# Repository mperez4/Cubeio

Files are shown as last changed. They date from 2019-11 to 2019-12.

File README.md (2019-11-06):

# Cubeio
An active meeting engagement tool designed to foster and facilitate decision-making, meaningful dialogue and equal input.
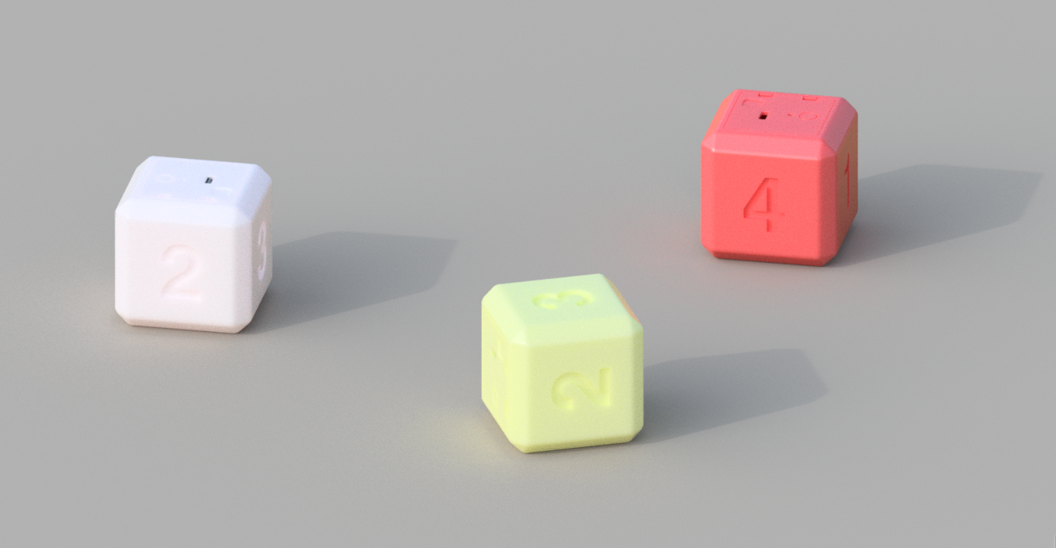
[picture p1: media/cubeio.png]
Cubeio


## Getting Started
If this is your first time using the particle, please refer to the [quickstart guide](https://docs.particle.io/quickstart/photon/). The following instructions are written for Mac. If you are using Particle's [web compiler](build.particle.io), search for the `Cubeio` library under libraries. 

### 1. Install [Particle CLI](https://docs.particle.io/tutorials/developer-tools/cli/)

```
$ npm install -g particle-cli
```

### 2. Create a new project

```
$ particle project create
```

### 3. Add library to your project
This should create the library scaffolding necessary to import the library from within your project directory. 

```
$ particle library add Cubeio
```

```
$ particle library view Cubeio
```

## Usage
Once you install the library through the Particle CLI, you should be ready to go.
```c++
#include "Cubeio.h"

Cubeio mycube(D6, D1, A1,A2,A3);
```
Your object declaration might be constructed differently depending on the hardware. Please view the hardware revision and pinouts under `/hardware`.
View the `/examples` and `/src` files to get detailed information about the library.

## Examples
There is a pretty handy script called `upload.sh` inside of every example. `upload.sh` puts the particle device in DFU mode, compiles the cpp file, and uploads the firmware to the device. Make sure that your cube's particle is connected via USB to your computer.
```bash
$ ./examples/set-calibration/upload.sh
```
This script was working well before I upgraded to Catalina... For now, you can use Particle's cloud compiler, which works fine it just takes longer... 

## Hardware
Cubeio uses an Analog Devices [ADXL325](https://www.analog.com/media/en/technical-documentation/data-sheets/ADXL325.pdf) 3-axis accelerometer to calculate the roll and pitch (±5 g) of the cube, a Microchip [MCP73831](http://ww1.microchip.com/downloads/en/DeviceDoc/20001984g.pdf) Li-Polymer charge managment controller, a Worldsemi [WS2812](https://cdn-shop.adafruit.com/datasheets/WS2812.pdf) RGB LED, a single [Schmitt-Trigger](https://datasheet.lcsc.com/szlcsc/ON-Semicon-ON-MC74VHC1G14DTT1G_C242264.pdf) inverter, and a button among other hardware components.
Please view the hardware revision and pinouts under `/hardware`.
You can use this library with any microcontroller if you are using an ADXLxxx chip on its own. You may set the analog pins to your microcontroller and it will work the same. This is intended for the cubeio hardware, so there are no default values set in the `Cubeio object()` object. This library will work for [this](https://www.adafruit.com/product/163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) device from Adafruit.

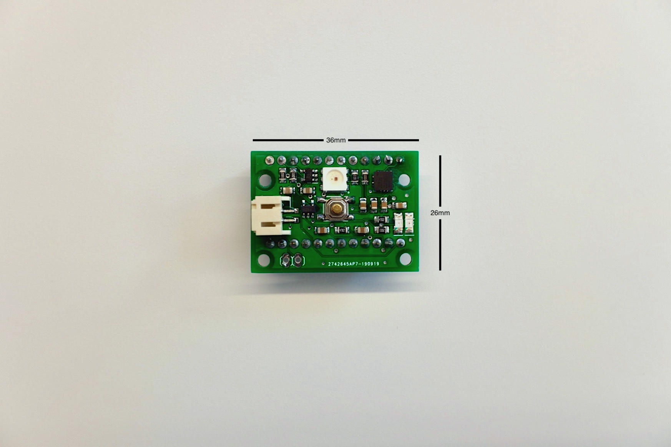
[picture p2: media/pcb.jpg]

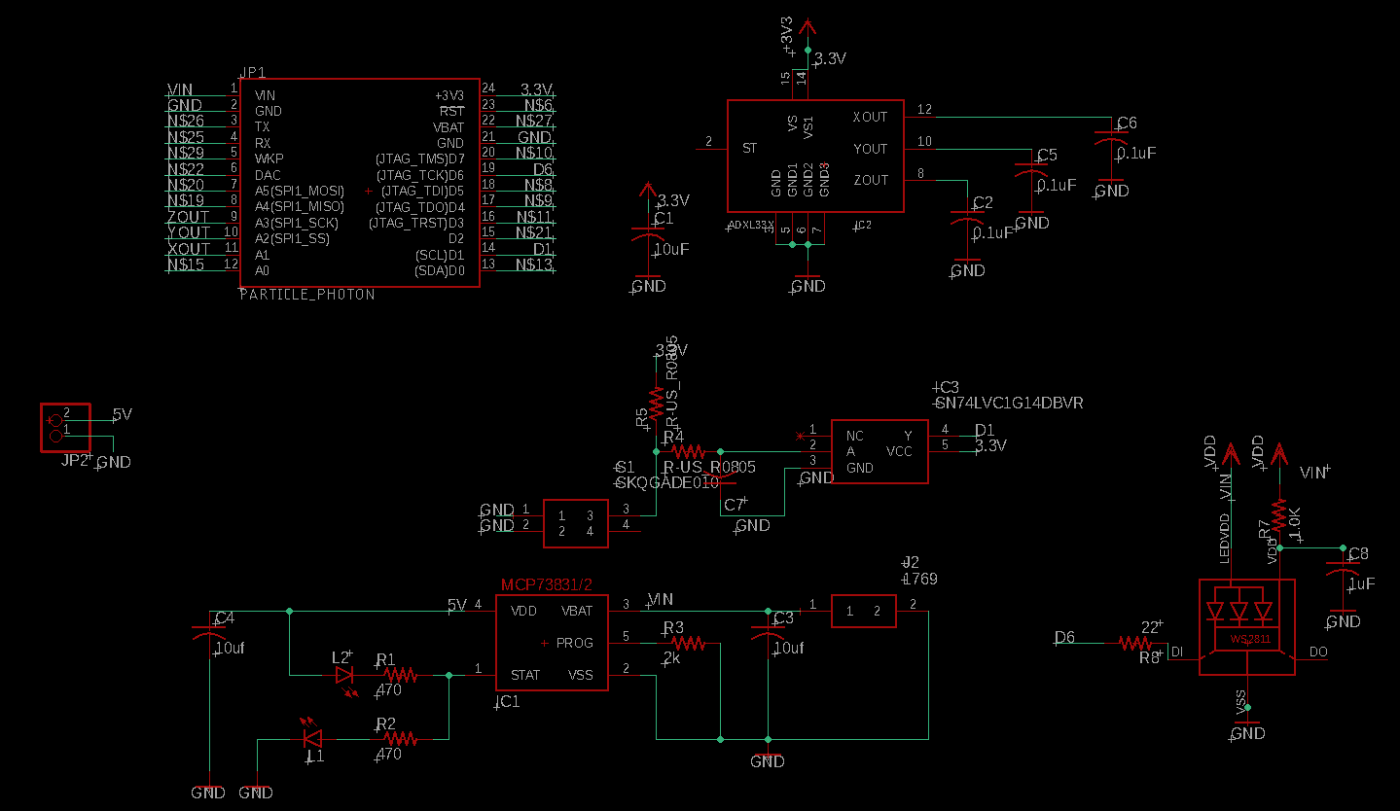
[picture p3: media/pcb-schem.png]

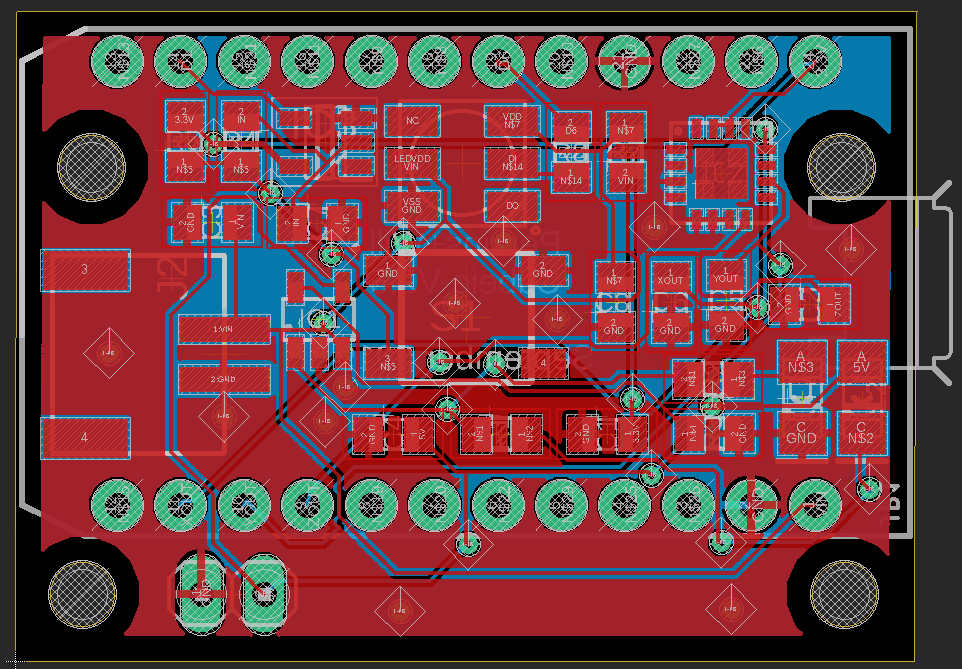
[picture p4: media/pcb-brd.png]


## Contribution
I don't think that the Particle CLI allows branching/merging of libraries from multiple users. This may change, so for now you are welcome to submit pull requests and i will publish the changes.

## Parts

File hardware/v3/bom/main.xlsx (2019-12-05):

Comment | Designator | Footprint | LCSC Part #（optional）
10uF | C1, C3, C4 | 0805 | C161260
100nF | C2, C5, C6, C7 | 0805 | C28233
1uF | C8 | 0805 | C28323
MCP73831T-2ATI/OT | IC1 | SOT-23-5 | C14879
ADXL325BCPZ-RL7 | IC2 | LFCSP-16 | C208133
SN74LVC1G14DBVR | IC3 | SOT-23-5 | C7835
AFC07-S06ECC-00 | J1 | 6P | C11083
TJ-S3216SW9TGLC9Y-A5 | L1 | 1206 | C192676
TJ-S3216SW9TGLC7K-A5 | L2 | 1206 | C192677
WS2812S | LED1 | 5050 | C114584
470ohms | R1, R2 | 0805 | C119076
2K | R3 | 0805 | C132365
10k | R4, R5 | 0805 | C84376
1K | R7 | 0805 | C95781
22Ohms | R8 | 0805 | C25295
TSA053G25-250T | S1 | SMD | C331512

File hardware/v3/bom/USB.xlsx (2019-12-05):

Comment | Designator | Footprint | LCSC Part #（optional）
ICC 10118192-0001LF | J3 | SMD | C132564
AFC07-S06ECC-00 | J1 | 6P | C11083

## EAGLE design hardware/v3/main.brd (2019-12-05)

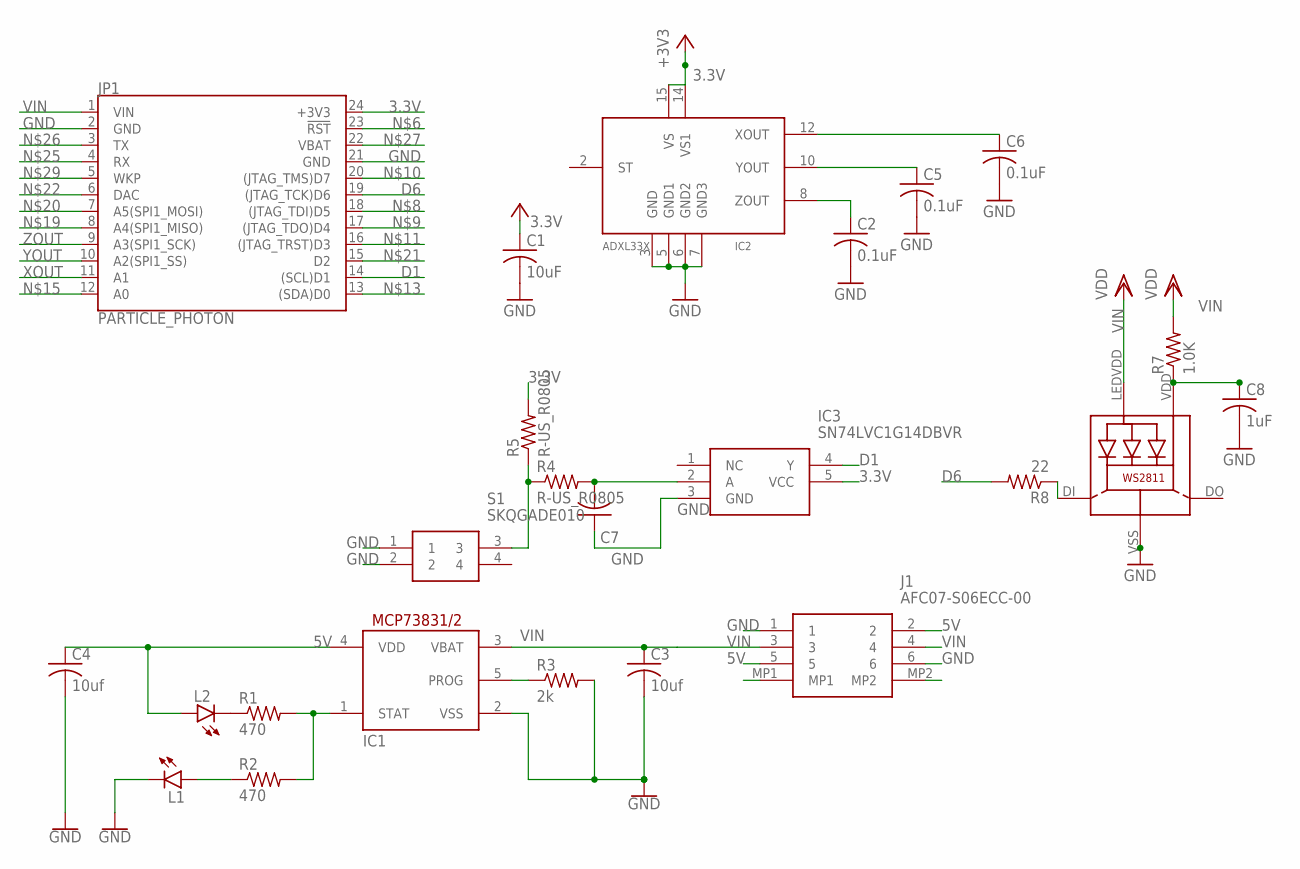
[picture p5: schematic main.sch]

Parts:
C1: 10uF; ADAFRUIT_C0805K
C2, C5, C6: 0.1uF; ADAFRUIT_C0805K
C3, C4: 10uf; ADAFRUIT_C0805K
C7: ADAFRUIT_C-USC0805K; ADAFRUIT_C0805K
C8: 1uF; ADAFRUIT_C0805K
IC1: MCP73831/OT; SOT23-5L
IC2: ADXL33X; 16LCSP
IC3: SN74LVC1G14DBVR; SOT95P280X145-5N
J1: AFC07-S06ECC-00; AFC07S06ECC00
JP1: PARTICLE_PHOTON
L1: green; FKIT-LED-1206
L2: blue; FKIT-LED-1206
LED1: WS28115050
R1, R2: 470; R0805
R3: 2k; R0805
R4, R5: R-US_R0805; R0805
R7: 1.0K; R0805
R8: 22; R0805
S1: SKQGADE010; SKQGAKE010

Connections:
3.3V: C1.1, IC2.14 (VS1), IC2.15 (VS), IC3.5 (VCC), JP1.24 (+3V3), R5.2
5V: C4.1, IC1.4 (VDD), J1.2, J1.5, L2.A
D1: IC3.4 (Y), JP1.14 ((SCL)D1)
D6: JP1.19 ((JTAG_TCK)D6), R8.2
GND: C1.2, C2.2, C3.2, C4.2, C5.2, C6.2, C7.1, C8.2, IC1.2 (VSS), IC2.3 (GND), IC2.5 (GND1), IC2.6 (GND2), IC2.7 (GND3), IC3.3 (GND), J1.1, J1.6, JP1.2 (GND), JP1.21 (GND), L1.C, LED1.VSS (GND), R3.2, S1.1, S1.2
IN: C7.2, IC3.2 (A), R4.2
unnamed: IC1.1 (STAT), R1.2, R2.2
unnamed: L2.C, R1.1
unnamed: L1.A, R2.1
unnamed: IC1.5 (PROG), R3.1
unnamed: R4.1, R5.1, S1.3
unnamed: C8.1, LED1.VDD, R7.1
unnamed: LED1.DI, R8.1
VIN: C3.1, IC1.3 (VBAT), J1.3, J1.4, JP1.1 (VIN), LED1.LEDVDD, R7.2
XOUT: C6.1, IC2.12 (XOUT), JP1.11 (A1)
YOUT: C5.1, IC2.10 (YOUT), JP1.10 (A2(SPI1_SS))
ZOUT: C2.1, IC2.8 (ZOUT), JP1.9 (A3(SPI1_SCK))

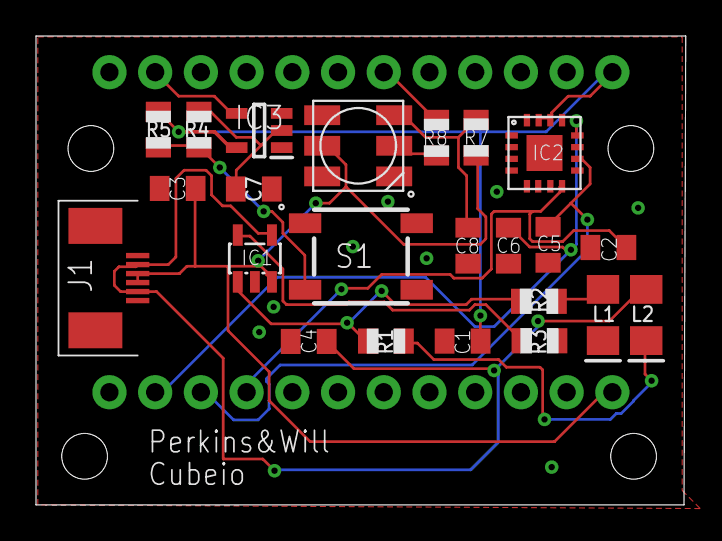
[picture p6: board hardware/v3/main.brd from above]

Board: 2 copper layers, 36.1 x 26.1 mm, 24 parts (1 on the bottom side), 17 nets.

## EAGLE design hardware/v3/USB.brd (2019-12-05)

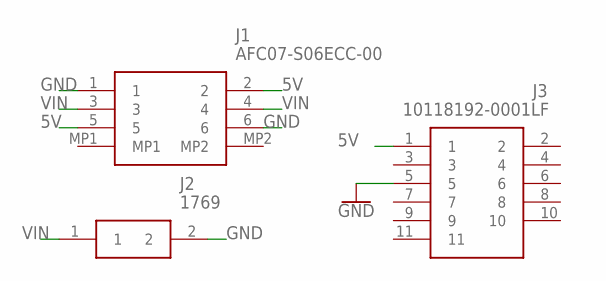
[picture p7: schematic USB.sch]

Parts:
J1: AFC07-S06ECC-00; AFC07S06ECC00
J2: 1769
J3: 10118192-0001LF; 101181920001LF

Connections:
5V: J1.2, J1.5, J3.1
GND: J1.1, J1.6, J2.2, J3.5
VIN: J1.3, J1.4, J2.1

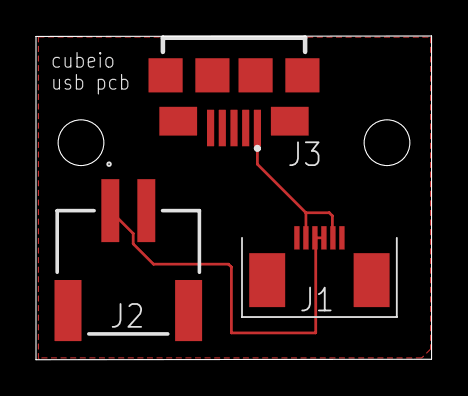
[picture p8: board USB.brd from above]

Board: 2 copper layers, 22.0 x 18.0 mm, 3 parts (0 on the bottom side), 3 nets.

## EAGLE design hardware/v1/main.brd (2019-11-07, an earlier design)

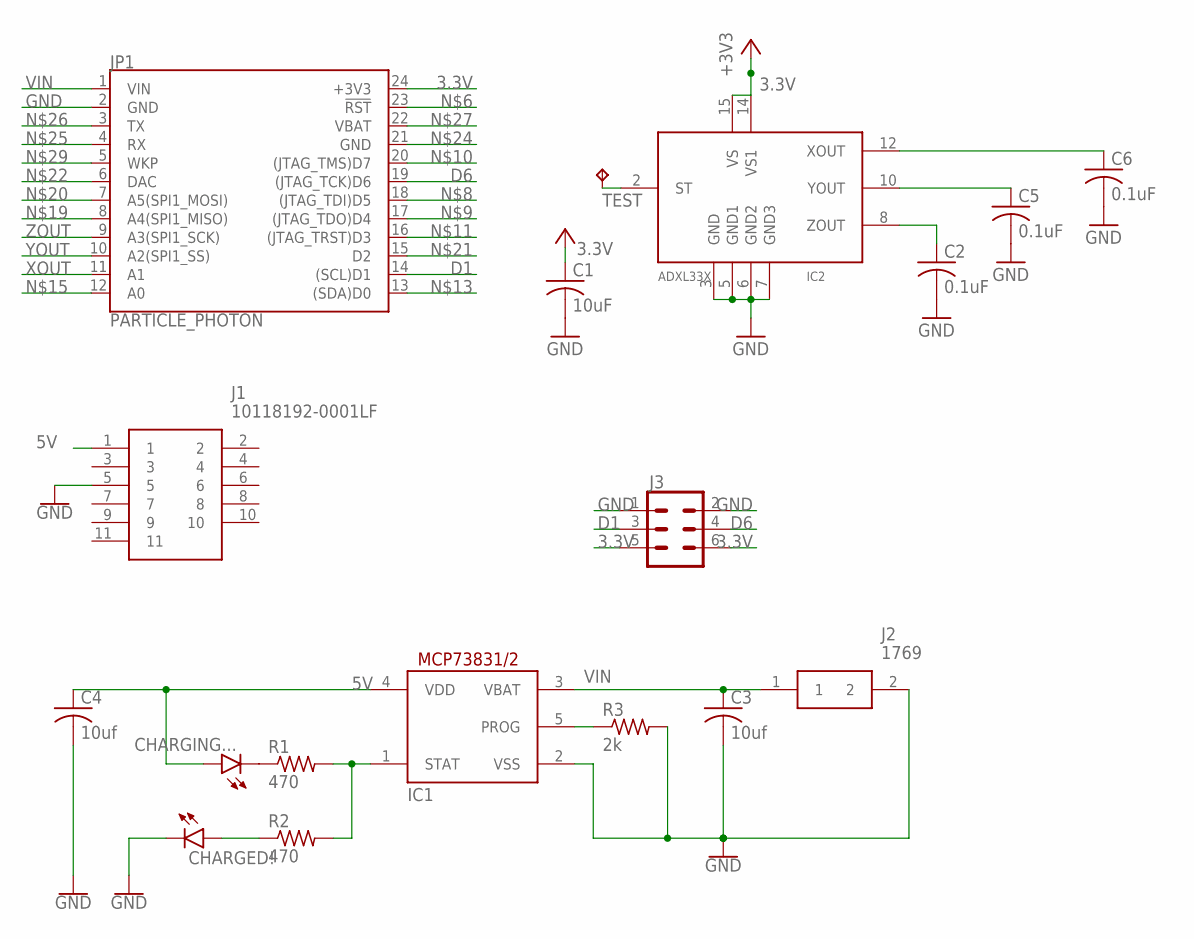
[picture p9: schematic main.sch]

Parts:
C1: 10uF; ADAFRUIT_C1206K
C2, C5, C6: 0.1uF; ADAFRUIT_C1206K
C3, C4: 10uf; C1206K
CHARGED!: green; FKIT-LED-1206
CHARGING...: blue; FKIT-LED-1206
IC1: MCP73831/OT; SOT23-5L
IC2: ADXL33X; 16LCSP
J1: 10118192-0001LF; 101181920001LF
J2: 1769
J3: CONN_03X2FEMALE_SMD; 2X3_SMD
JP1: PARTICLE_PHOTON
R1, R2: 470; M1206
R3: 2k; M1206
TEST: TPTP14R; TP14R

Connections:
3.3V: C1.1, IC2.14 (VS1), IC2.15 (VS), J3.5, J3.6, JP1.24 (+3V3)
5V: C4.1, CHARGING....A, IC1.4 (VDD), J1.1
D1: J3.3, JP1.14 ((SCL)D1)
D6: J3.4, JP1.19 ((JTAG_TCK)D6)
GND: C1.2, C2.2, C3.2, C4.2, C5.2, C6.2, CHARGED!.C, IC1.2 (VSS), IC2.3 (GND), IC2.5 (GND1), IC2.6 (GND2), IC2.7 (GND3), J1.5, J2.2, J3.1, J3.2, JP1.2 (GND), R3.2
unnamed: IC1.1 (STAT), R1.2, R2.2
unnamed: CHARGING....C, R1.1
unnamed: CHARGED!.A, R2.1
unnamed: IC1.5 (PROG), R3.1
TEST: IC2.2 (ST), TEST.TP
VIN: C3.1, IC1.3 (VBAT), J2.1, JP1.1 (VIN)
XOUT: C6.1, IC2.12 (XOUT), JP1.11 (A1)
YOUT: C5.1, IC2.10 (YOUT), JP1.10 (A2(SPI1_SS))
ZOUT: C2.1, IC2.8 (ZOUT), JP1.9 (A3(SPI1_SCK))

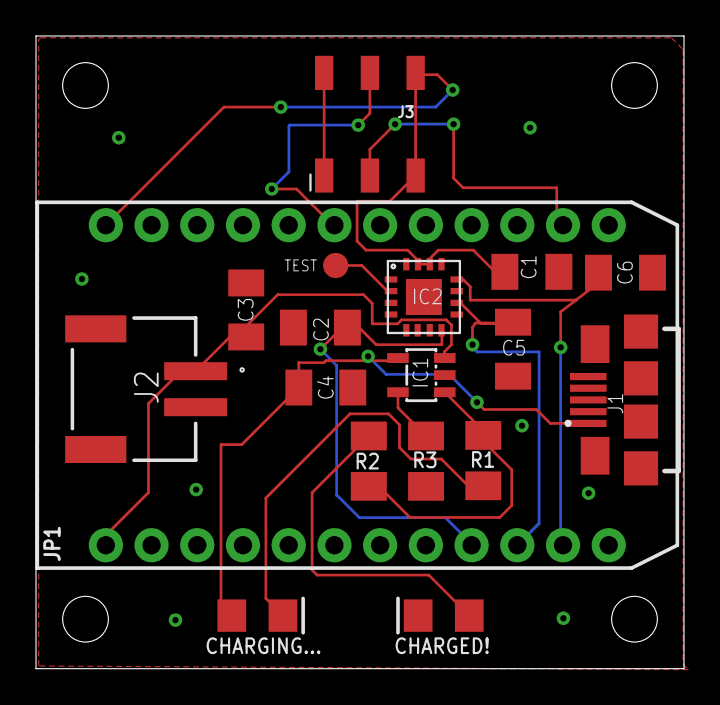
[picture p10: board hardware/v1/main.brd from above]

Board: 2 copper layers, 36.0 x 35.1 mm, 18 parts (0 on the bottom side), 14 nets.

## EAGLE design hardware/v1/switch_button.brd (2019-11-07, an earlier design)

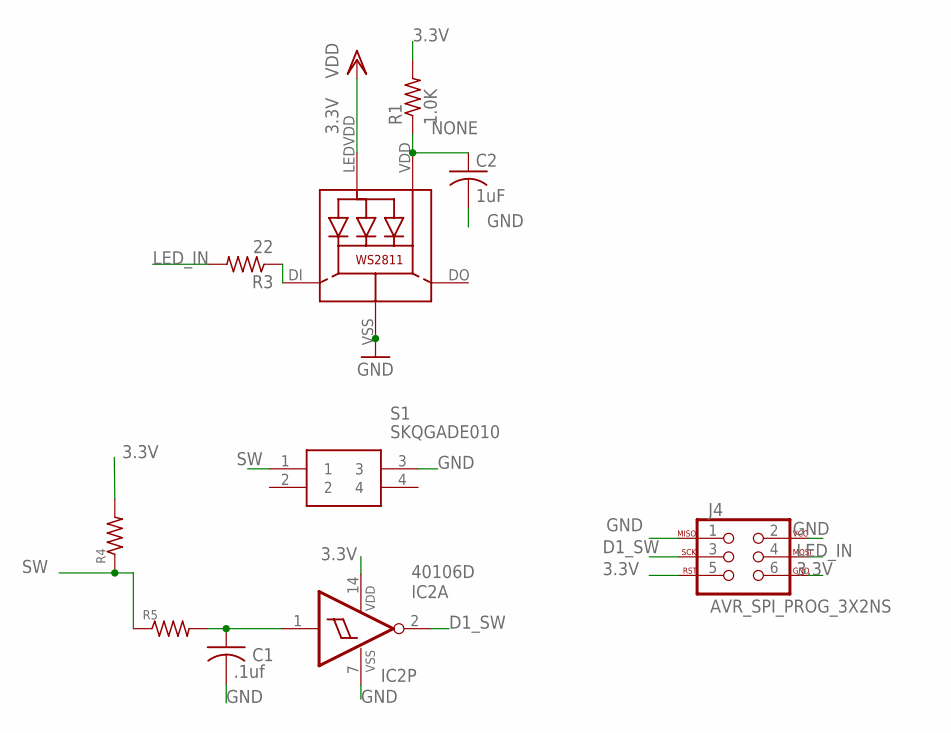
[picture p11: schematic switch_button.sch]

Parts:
C1: .1uf; ADAFRUIT_C1206K
C2: 1uF; C1206K
IC2: 40106D; SO14
J4: AVR_SPI_PROG_3X2NS; 2X3-NS
LED1: WS28115050
R1: 1.0K; R1206FAB
R3: 22; M1206
R4, R5: 10k; M1206
S1: SKQGADE010; SKQGAKE010

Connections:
3.3V: IC2.14 (VDD), J4.5, J4.6, LED1.LEDVDD, R1.2, R4.2
D1_SW: IC2.2 (O), J4.3
GND: C1.2, C2.2, IC2.7 (VSS), J4.1, J4.2, LED1.VSS (GND), S1.3
LED_IN: J4.4, R3.2
unnamed: LED1.DI, R3.1
unnamed: C1.1, IC2.1 (I), R5.2
NONE: C2.1, LED1.VDD, R1.1
SW: R4.1, R5.1, S1.1

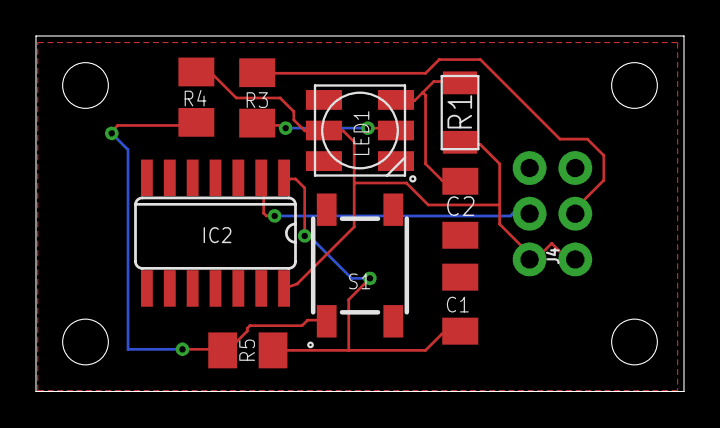
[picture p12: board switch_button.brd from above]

Board: 2 copper layers, 36.0 x 19.8 mm, 10 parts (0 on the bottom side), 8 nets.

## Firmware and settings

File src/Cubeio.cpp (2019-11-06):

#include "Particle.h"
#include "Cubeio.h"
#include "math.h"
#define PIXEL_TYPE WS2812B


Cubeio::Cubeio(const uint8_t switchPin, const uint8_t ledPin, const uint8_t xPin, const uint8_t yPin, const uint8_t zPin)
{
  _switchPin = switchPin;
  _ledPin = ledPin;
  _xPin = xPin;
  _yPin = yPin;
  _zPin = zPin;

  pinMode(_switchPin, INPUT_PULLUP);
  pinMode(D7, OUTPUT);

  externalLed = new Adafruit_NeoPixel(1,1, PIXEL_TYPE);
  externalLed->begin();
  loadCalibrationValuesFromEEPROM();
}

char Cubeio::getActiveSide(){
  calculateRollPitch();
  for (int i = 0; i < 6; ++i){
    if (roll > sides_array[i][1] - _threshold && roll < sides_array[i][1] + _threshold &&
        pitch > sides_array[i][0] - _threshold && pitch < sides_array[i][0] + _threshold){
        active_side = side[i];
        //Serial.printlnf("Pitch: %d, %d Roll: %d, %d Side: %d",pitch, sides_array[i][0], roll, sides_array[i][1], active_side);
    }
  }
  return active_side;
}

void Cubeio::publishOnChange(String eventName){
  _currentside = getActiveSide();
  if(_prevside != _currentside){
    Particle.publish(eventName, String(_currentside));
    delay(1000);//so that it doesnt spam the particle api
  }
  _prevside = _currentside;
}

void Cubeio::getCalibrationResult(){
  for(int i = 0; i < 6; i++){
    Serial.printlnf("Side: %d Pitch: %d Roll: %d", side[i], sides_array[i][0], sides_array[i][1]);
  }
}

void Cubeio::loadCalibrationValuesFromEEPROM(){
  for(int i =0; i < 6; i++){
    EEPROM.get(addr + i*sizeof(calibrationValues), valueSet);
    sides_array[i][0] = valueSet.pitch;
    sides_array[i][1] = valueSet.roll;
  }
}

void Cubeio::setLedColor(int r, int g, int b){
  RGB.color(r,g,b);
  externalLed->setPixelColor(0, externalLed->Color(r, g , b));
  externalLed->show();
}

void Cubeio::setLedBrightness(int brightness){
  RGB.brightness(brightness);
  externalLed->setBrightness(brightness);
}

void Cubeio::setFrequency(int frequency){
  _frequency = frequency;
}

void Cubeio::setThreshold(int threshold){
  _threshold = threshold;
}

void Cubeio::enableLedControl(){
  RGB.control(true);
}

void Cubeio::disableLedControl(){
  RGB.control(false);
}

void Cubeio::interruptHandler(){
  state = !state;
  digitalWrite(D7, state);
}

void Cubeio::attachButton(InterruptMode _mode){
  attachInterrupt(_switchPin, &Cubeio::interruptHandler, this, _mode);
}

void Cubeio::detachButton(){
  detachInterrupt(_switchPin);
}

bool Cubeio::buttonPressed(){
  if(!state){
    return false;
  }
  else return true;
}

void Cubeio::readSensorData(int x, int y, int z){
  x_value = analogRead(x);
  y_value = analogRead(y);
  z_value = analogRead(z);
}

void Cubeio::calculateRollPitch(){
  readSensorData(_xPin, _yPin, _zPin);

  x_g_value = ((((double)(x_value * 3.3) / 4095) - 1.65) / 0.330);
  y_g_value = ((((double)(y_value * 3.3) / 4095) - 1.65) / 0.330);
  z_g_value = ((((double)(z_value * 3.3) / 4095) - 1.80) / 0.330);

  roll = (((atan2(y_g_value, z_g_value) * 180) / 3.14) + 180);
  pitch = (((atan2(z_g_value, x_g_value) * 180) / 3.14) + 180);
}

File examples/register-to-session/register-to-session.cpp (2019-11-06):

//creates a button interrupt with onboard hardware, 
//and sets it as a mode selector

#include "Cubeio.h"

Cubeio mycube(D6, D1, A1,A2,A3);

int _case = 0;
unsigned long start_time;
unsigned long current_time;
unsigned long elapsed_time;
const int mode_threshold = 2000;

int active_side;
int session_list[2];
bool isRegistered = false;
bool isRegistering = false;
bool button_state = false;
static volatile int registry = 0;
static volatile int registry_size = 2;
String registration_id;

String status = "unpaired"; //particle variable to manage status

int registrationResponse(String command);
int modeSelect(int current_case);
void modeHandler(void);

void setup(){
  Serial.begin(9600);
  Particle.variable("status", status);
  Particle.function("registration_response", registrationResponse);
  mycube.enableLedControl();
  mycube.setLedBrightness(20);
  mycube.attachButton(CHANGE);
  mycube.setThreshold(30);
}

void loop(){
  active_side = mycube.getActiveSide();
  modeHandler();
  switch (_case){
    case 1://registration mode
      mycube.setLedColor(0,255,0);
      //collects sequence of two numbers, sends it to particle. backend responds
      //with a 0 or 1
      if (registry >= registry_size){
        Serial.println("Exiting registration mode...");
        isRegistering = false;
        registry = 0;
        for(int i = 0; i <= registry_size; i++){
          registration_id.concat(session_list[i]);
        }
        Particle.publish("reg_id", registration_id);
        registration_id = "";
      }
    break;
    case 2://is registered
      mycube.setLedColor(255,0,0);
    break;
    default:
      mycube.setLedColor(255,255,255);
    break;
  }
}

//listens for either a short(two seconds) press, a long(four seconds) press, or
//a longest(six seconds) press and returns a value that is used in a switch statment
int modeSelect(int current_case){
  //registration mode
  if(elapsed_time > mode_threshold && elapsed_time < mode_threshold * 2 && !isRegistering){
    mycube.setLedColor(0,255,0);
    isRegistering = true;
    return 1;
  }
  if(elapsed_time > mode_threshold * 2 && elapsed_time < mode_threshold * 3 && !isRegistering){
    mycube.setLedColor(255,0,0);
    return 2;
  }
  if(elapsed_time > mode_threshold * 3 && elapsed_time < mode_threshold * 4 && !isRegistering){
    mycube.setLedColor(255,255,255);
    return 0;
  }
  else{
    return current_case;
  }
}
//unfortunately we cannot make a handler while using interrupts,
//so the function needs to be called.
void modeHandler(){
  _case = modeSelect(_case);
  if(mycube.buttonPressed()){
    start_time = millis();
    elapsed_time =  start_time - current_time;
    if(isRegistering){
      session_list[registry] = active_side;
      Serial.printlnf("Registered: %d Registry: %d", active_side, registry);
      registry++;
    }
    delay(500);
  }else{
    current_time = millis();
  }
}

//handles response from the backend. If the registration sequence 
//it will return the corresponding case. Should be inside modeSelect if
//registration mode is active. 
int registrationResponse(String command){
  if(command == "0"){
    status = "unregistered";
    isRegistered = false;
    //change case
  }if(command == "1"){
    status = "registered";
    isRegistered = true;
    //change case
  }
}

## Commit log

2019-10-23 external led working.
2019-10-23 added brighness on external led
2019-10-23 added button functionality
2019-10-30 reading successfully from EEPROM to set default calibration values
2019-10-30 button working
2019-10-30 printing calibration results
2019-10-31 fixed active side bug
    [Cubeio.cpp, post-on-press.cpp]
2019-11-07 added eagle files
    [USB.brd, USB.sch, main.brd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]
2019-12-05 added v3 hardware files
    [USB.brd, USB.sch, USB.xlsx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]

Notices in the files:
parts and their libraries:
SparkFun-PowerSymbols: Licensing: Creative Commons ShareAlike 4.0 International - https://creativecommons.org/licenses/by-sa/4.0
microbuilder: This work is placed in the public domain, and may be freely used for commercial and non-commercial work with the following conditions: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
